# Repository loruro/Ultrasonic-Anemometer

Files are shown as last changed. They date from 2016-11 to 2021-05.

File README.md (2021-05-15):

# Ultrasonic Anemometer

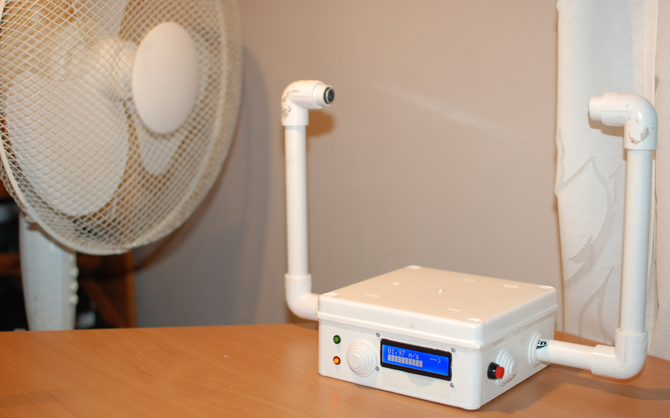
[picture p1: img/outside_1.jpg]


This is Ultrasonic Anemometer project based on AVR ATmega microcontroller.

## Principle of operation

Device measures wind velocity using ultrasounds. Two ultrasonic transducers installed on the end of both pipes send 40 kHz ultrasound signal between each other. Normally the velocity of this signal is the same for both directions. It is equal to the speed of sound, which depends mainly on the air temperature. For dry air and 1000 hPa pressure it can be calculated from:



where:
* vₚ - speed of sound [m/s]
* θ - air temperature [°C]

At 20 °C it is 343,96 m/s.

If there is a wind, it alters velocity of sound wave propagating in direction parallel to the wind:

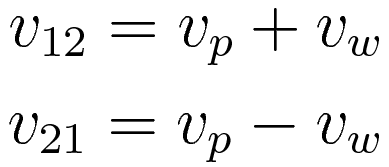
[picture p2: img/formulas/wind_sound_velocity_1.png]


where:
* v₁₂ - velocity of sound wave between point 1 and point 2
* v₂₁ - velocity of sound wave between point 2 and point 1
* vₚ - speed of sound
* vᵥᵥ - speed of wind

Above equations can be transformed into:

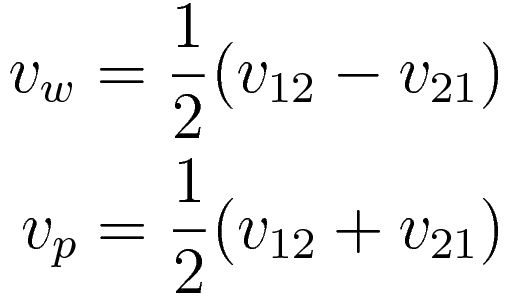
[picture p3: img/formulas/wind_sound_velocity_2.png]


The velocity of sound wave can be acquired by measuring time of flight of this wave between ultrasonic transducers. This is what this device does. First transducer emits ultrasonic impulse and second one receives it. Time between those events is measured and later the situation is reversed. Second transducers emits and first one receives.  
Knowing distance between those transducers, velocity of sound can be finally calculated.

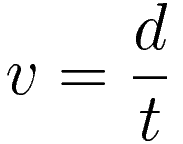
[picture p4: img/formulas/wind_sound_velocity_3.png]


where:
* d - distance between transducers
* t - time of flight

Velocities in previous equations can be substituted by above time formula:

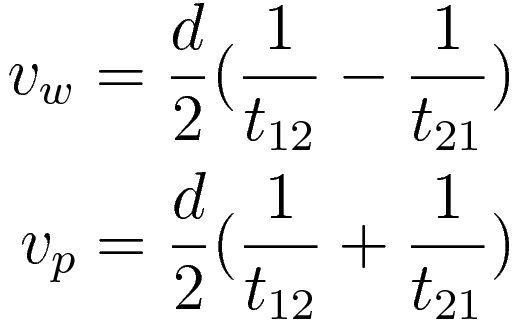
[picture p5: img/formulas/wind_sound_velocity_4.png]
  

Anemometer has only two ultrasonic transducers. Therefore, it can only measure wind speed in one direction (parallel to line containing both transducers). Measurement in more dimensions can be achievied by adding more transducers.

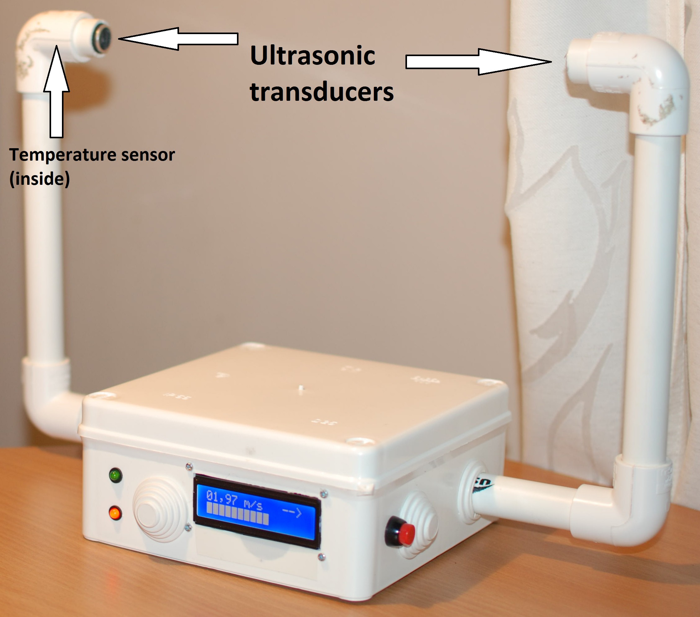
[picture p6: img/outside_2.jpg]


Device displays calculated wind speed and its direction on [HD44780 LCD](https://en.wikipedia.org/wiki/Hitachi_HD44780_LCD_controller) display. Under speed value there is a progress bar to next measured value. Unfortunately it takes quite a lot of time to perform all the signal processing calculations on this ATmega (about 46 seconds).  
Red LED is lit while power is supplied to the device. Green LED is blinking while the device is working correctly.  
Red button on the right performs calibration procedure. After pressing button for 2 seconds, [envelope](https://en.wikipedia.org/wiki/Envelope_%28waves%29) will be calculated of the next set of samples acquired by transducers. The result will be stored in EEPROM and used later for signal processing. This has to be done while there is no wind. Along with samples, temperature from DS1820 sensor is also acquired and stored. This calibration data will survive shutdown of the device because of storage in EEPROM.  
On the left side of the device there is a socket for power supply.

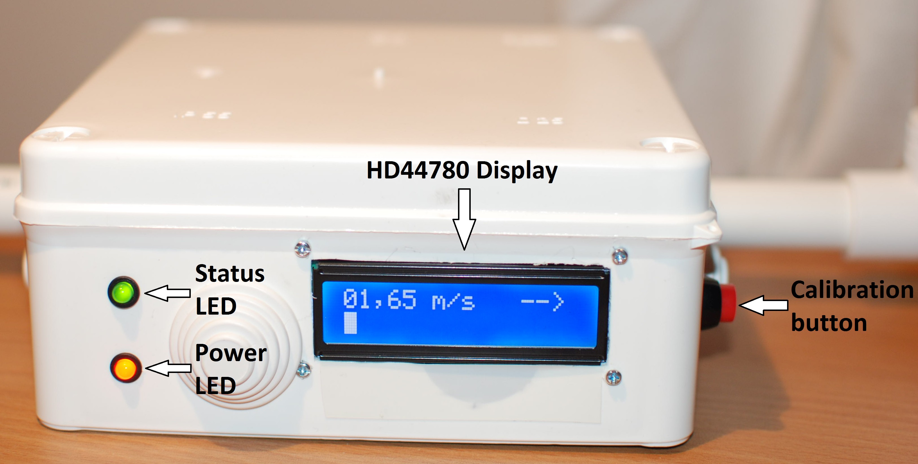
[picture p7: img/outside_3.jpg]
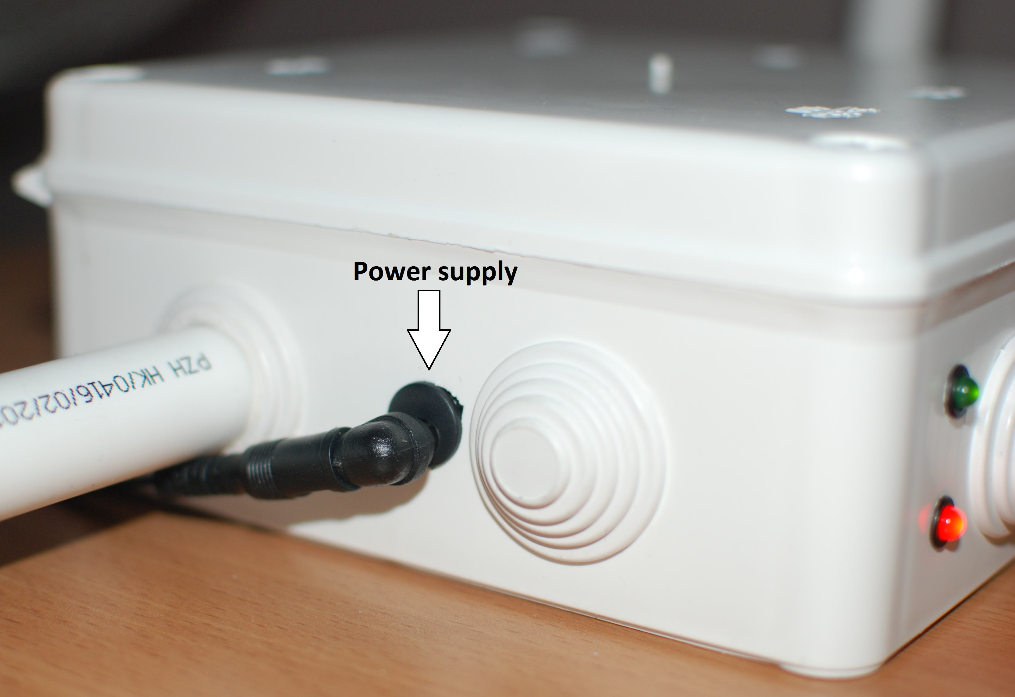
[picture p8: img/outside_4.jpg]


## Hardware

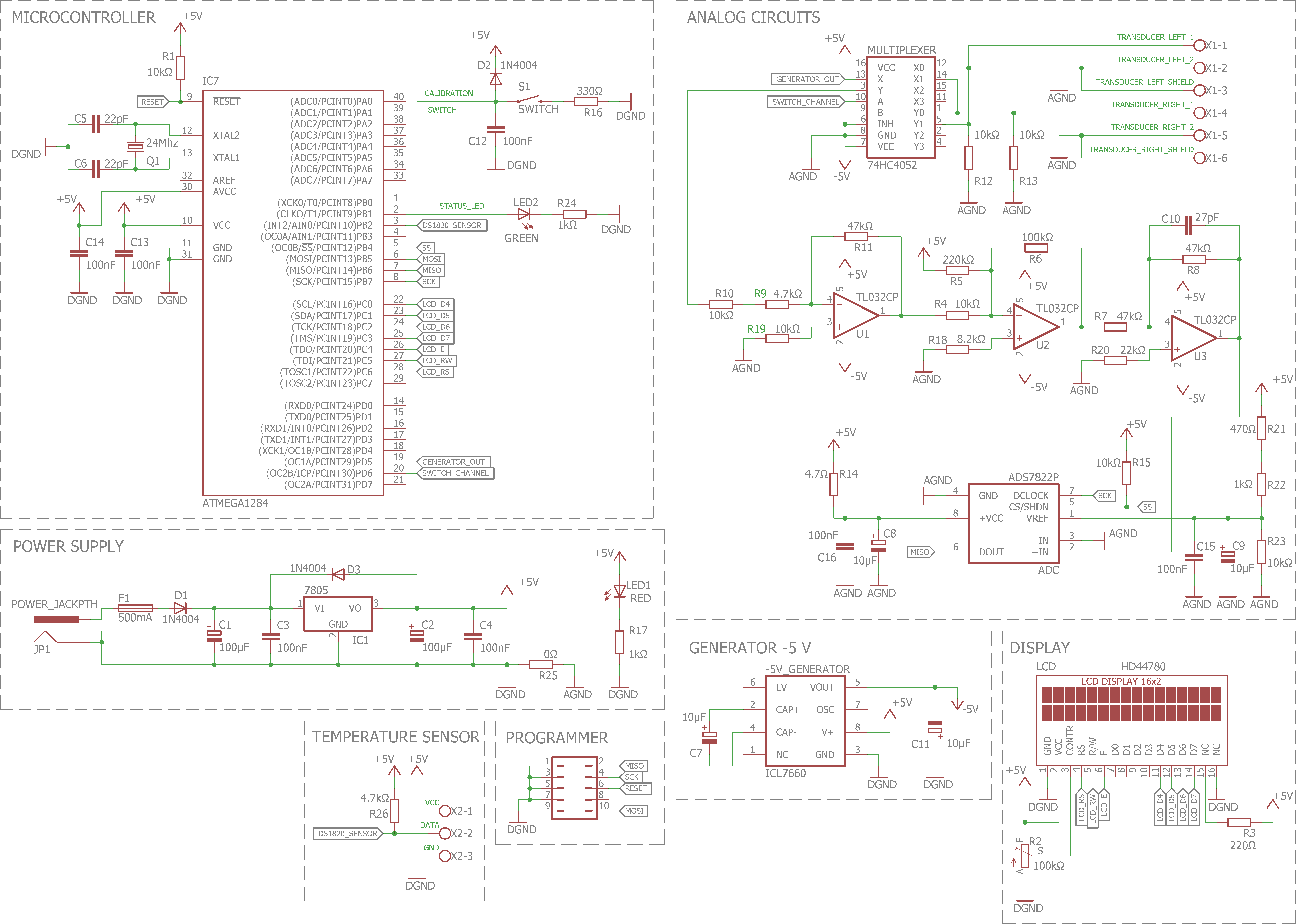
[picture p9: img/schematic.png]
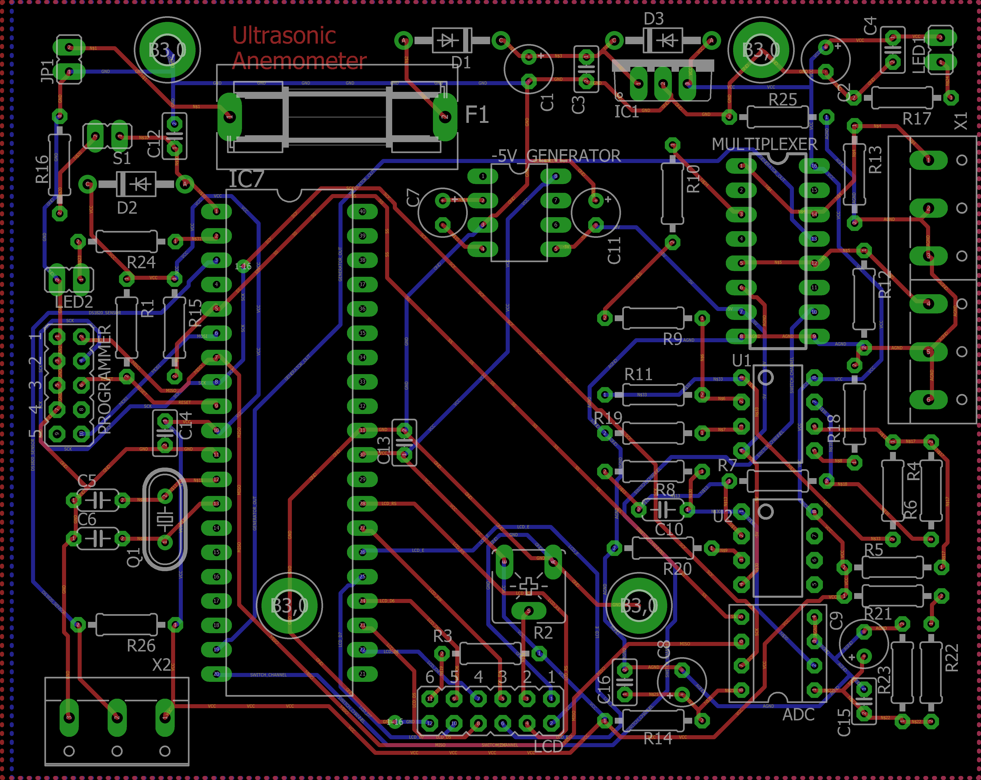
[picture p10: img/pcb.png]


Main part of the device is the AVR [ATmega1284](http://www.atmel.com/devices/atmega1284.aspx) microcontroller. It is slightly overclocked for a better performance. I used 24 MHz quartz crystal (official max. frequency is 20 MHz). Controller is programmed with ISP interface. I used simple and cheap [USBasp](http://www.fischl.de/usbasp/) programmer for it.  
Calibration button was connected together with resistor, capacitor and diode which do hardware [debouncing](https://en.wikipedia.org/wiki/Switch#Contact_bounce).  
All of the electronics are powered by 5 V supplied by onboard 7805 voltage regulator. It takes voltage straight from power socket. I used external 9 V power supply, but slightly higher voltage would be OK too (not too much to not overheat 7805 regulator). Along with it there is simple protection overcurrent and inverted voltage. Also there is ICL7660 -5 V voltage generator. It's used for powering multiplexer and operational amplifiers.  
HD44780 display is connected in 4-bit mode and busy bit reading.  
DS1820 temperature sensor uses 1-Wire interface, but has option for powering it via additional VDD pin. I used this option for better stability.  
Analog part of the device needs more explanation. Some of the signals here were measured by an oscilloscope. Microcontroller sends square wave through GENERATOR_OUT line to ultrasonic transducers.

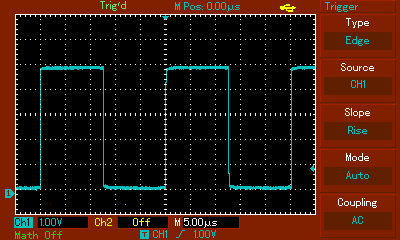
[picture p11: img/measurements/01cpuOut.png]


Multiplexer 74HC4052 directs it to either left or right transducer. Multiplexer is controlled by SWITCH_CHANNEL from ATmega. Transducers used in project are narrowband and designed for 40 kHz signal. Experimentally I found out that 40268 Hz signal gives the best amplitude. Transducers are connected with board by shielded cable. While signal from microcontroller is directed to one of them, signal from the other one is directed by multiplexer to amplifiers. Here is the signal before them:

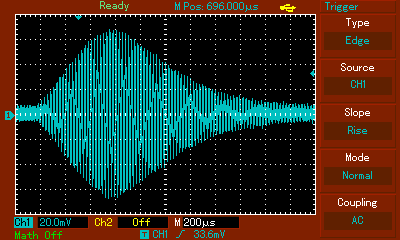
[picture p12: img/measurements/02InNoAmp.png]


First is an [inverting amplifier](https://en.wikipedia.org/wiki/Operational_amplifier_applications#Inverting_amplifier):



Amplified signal:

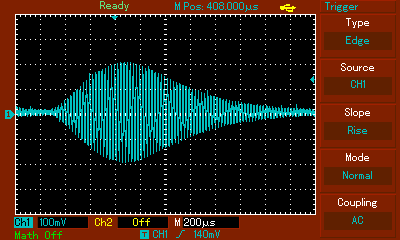
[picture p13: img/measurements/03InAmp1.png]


Later signal goes to [summing amplifier](https://en.wikipedia.org/wiki/Operational_amplifier_applications#Summing_amplifier), which again amplifies and adds offset to it. Entire signal has to be voltage positive because ADC used in the device cannot work with negative voltage.



Amplified signal:

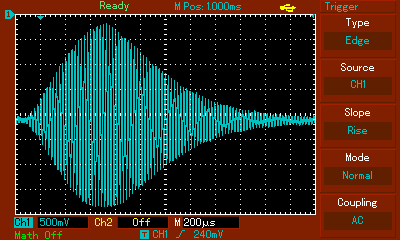
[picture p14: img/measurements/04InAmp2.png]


For final step I used [integrator](https://en.wikipedia.org/wiki/Operational_amplifier_applications#Inverting_integrator), which acts as low-pass filter. Any frequencies which are higher than our ultrasonic signal should be filtered out. Transfer function of the filter:



And its Bode plot:

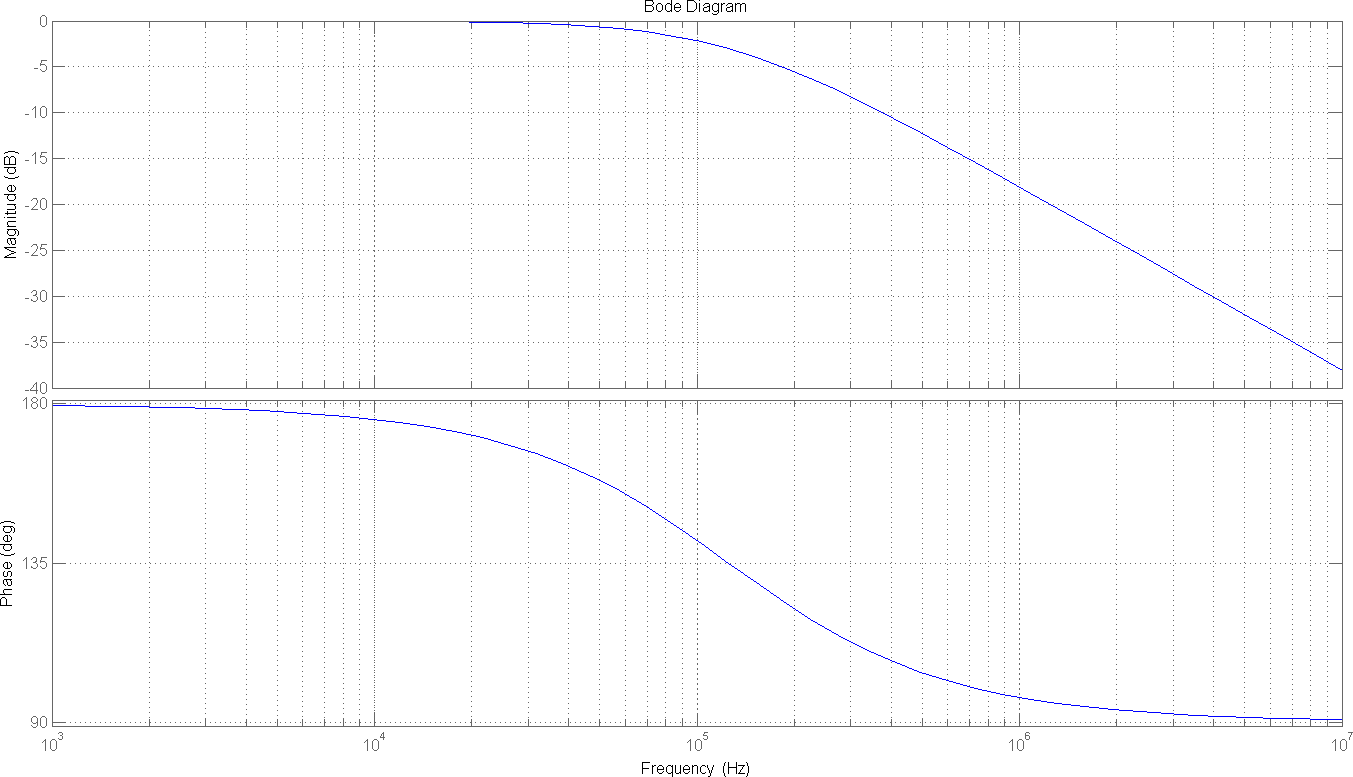
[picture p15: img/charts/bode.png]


Signal after filtering:

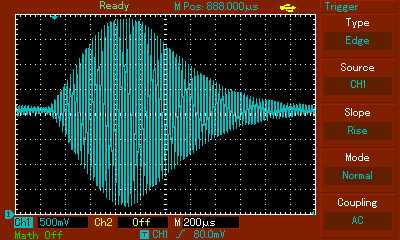
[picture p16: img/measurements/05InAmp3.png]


After all the operational amplifiers, signal finally goes to ADS7822P analog-to-digital converter. It sends converted digital signal to microcontroller through SPI interface. ATmega here is a master. This ADC has a resolution of 12 bits and max. frequency of 200 kHz. Because of clock dividers in ATmega and clock cycles needed to handle SPI, I managed to get sampling frequency of 157.9 kHz. [Nyquist–Shannon–Kotelnikov sampling theorem](https://en.wikipedia.org/wiki/Nyquist%E2%80%93Shannon_sampling_theorem) states that the sampling frequency should be at least 80536 Hz, so it is fulfilled. Analog signal has maximum value of about 4 V, so to increase voltage resolution I attached voltage divider to VREF pin of ADC, which gives voltage of about 4.359 V. This results in voltage resolution of 1.064 mV.  
Analog part of the device uses different ground than the rest of the device. It reduces noise derived from high frequency digital signals. Digital ground and analog ground are connected together at one point, close to the power supply.

Electrical schematic and PCB layout were designed using [EAGLE](https://cadsoft.io/) application. Tracks on PCB were designed using EAGLE Autorouter. That's why it's so ugly :)  
Photos of interior:

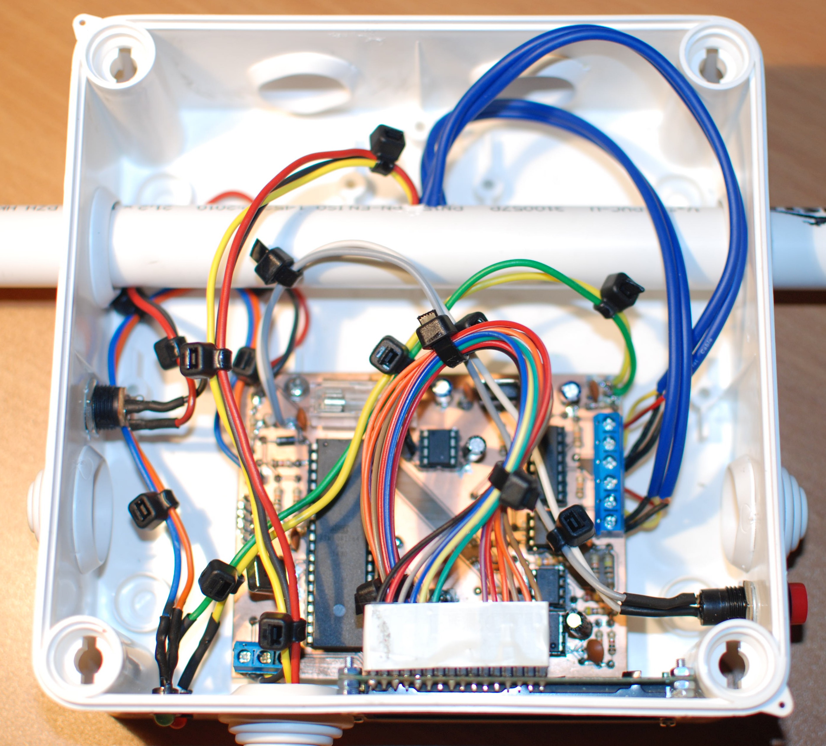
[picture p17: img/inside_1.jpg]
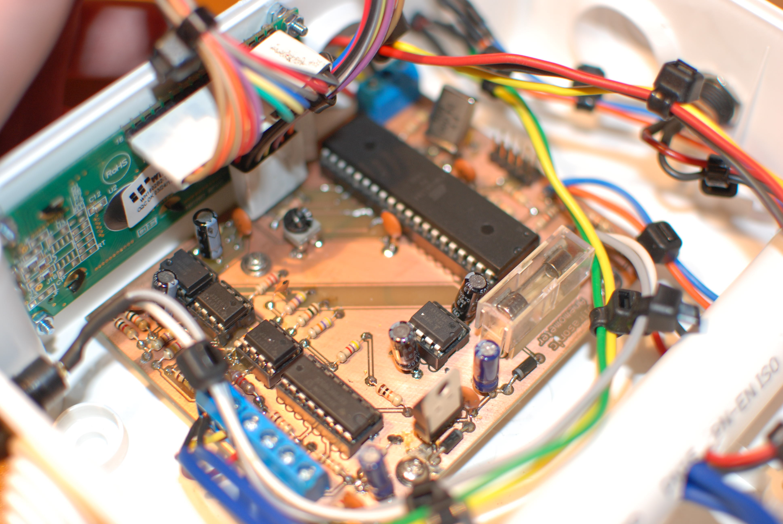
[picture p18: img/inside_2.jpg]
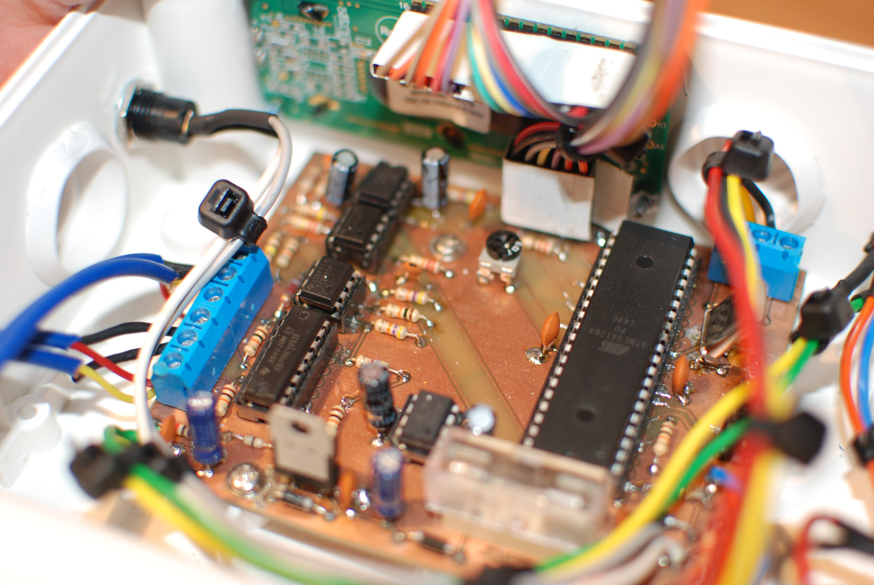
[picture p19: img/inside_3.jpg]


## Signal processing

After acquiring by microcontroller, digital samples look like this:

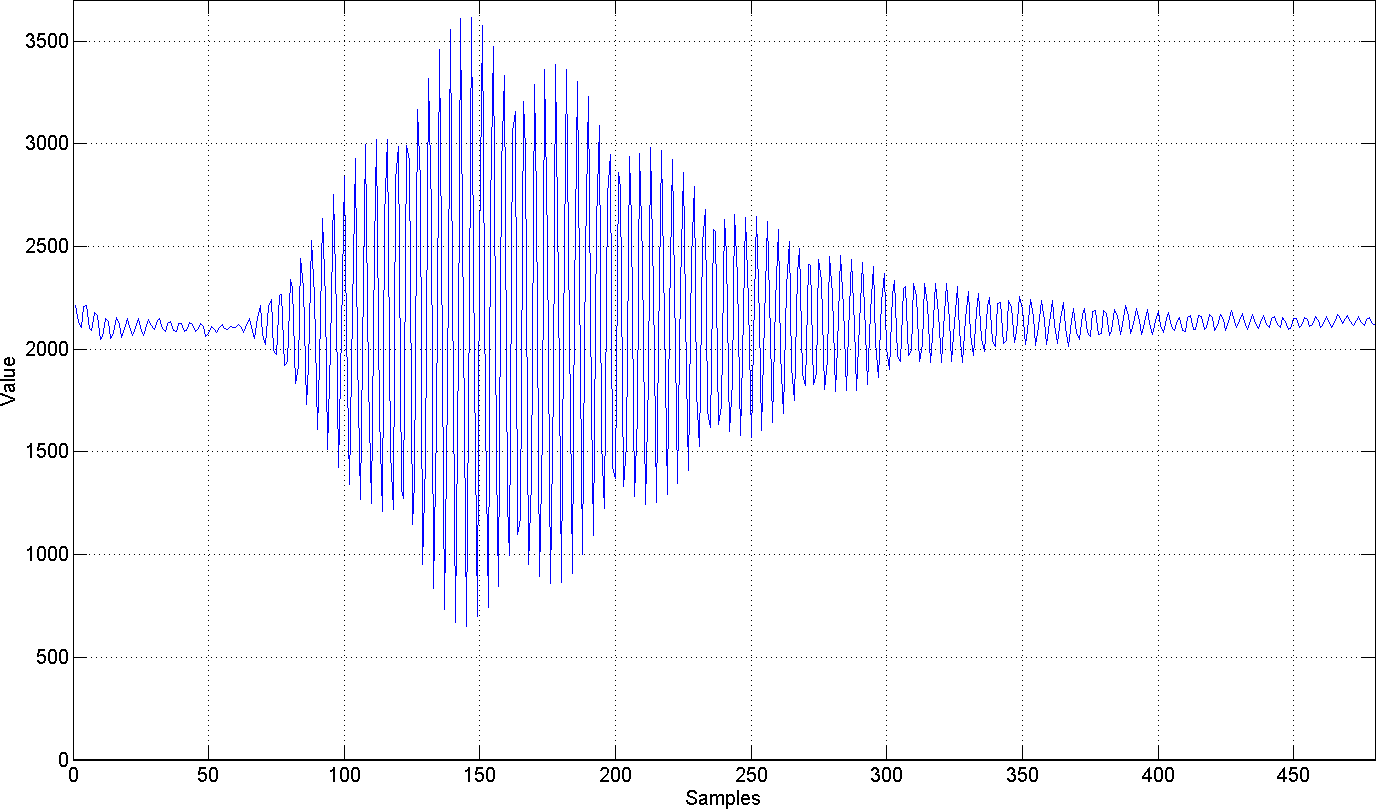
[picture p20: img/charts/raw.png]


Those samples should be analyzed without offset, so average value is calculated and subtracted from them:

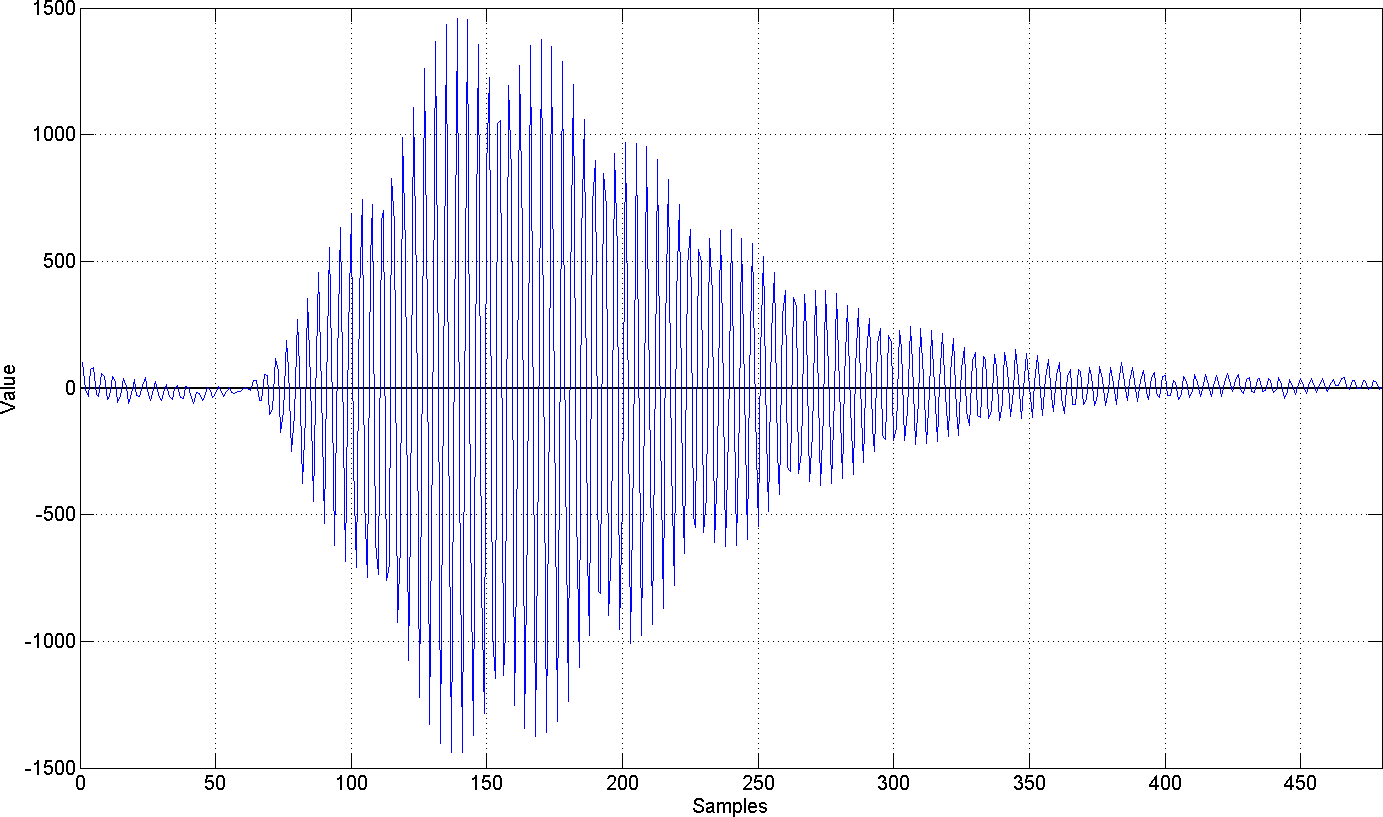
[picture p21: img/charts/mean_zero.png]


For getting precise time of flight of ultrasonic impulse I decided to calculate envelope of the acquired signal and [cross correlate](https://en.wikipedia.org/wiki/Cross-correlation) it with the calibration signal stored in EEPROM. To get envelope of signal, a magnitude of its [analytic representation](https://en.wikipedia.org/wiki/Analytic_signal) can be calculated. To get analytic signal, [Hilbert transform](https://en.wikipedia.org/wiki/Hilbert_transform) has to be calculated first. I used the following discrete formula to acquire it:

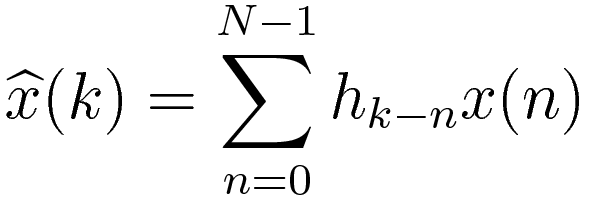
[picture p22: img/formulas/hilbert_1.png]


where:

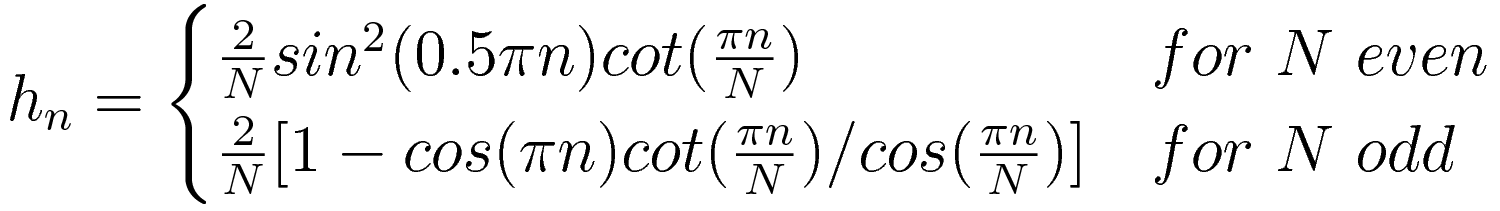
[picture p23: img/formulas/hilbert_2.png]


and
* x - original signal
* N - number of samples

Analytic signal can now be calculated with the following formula:



Result:

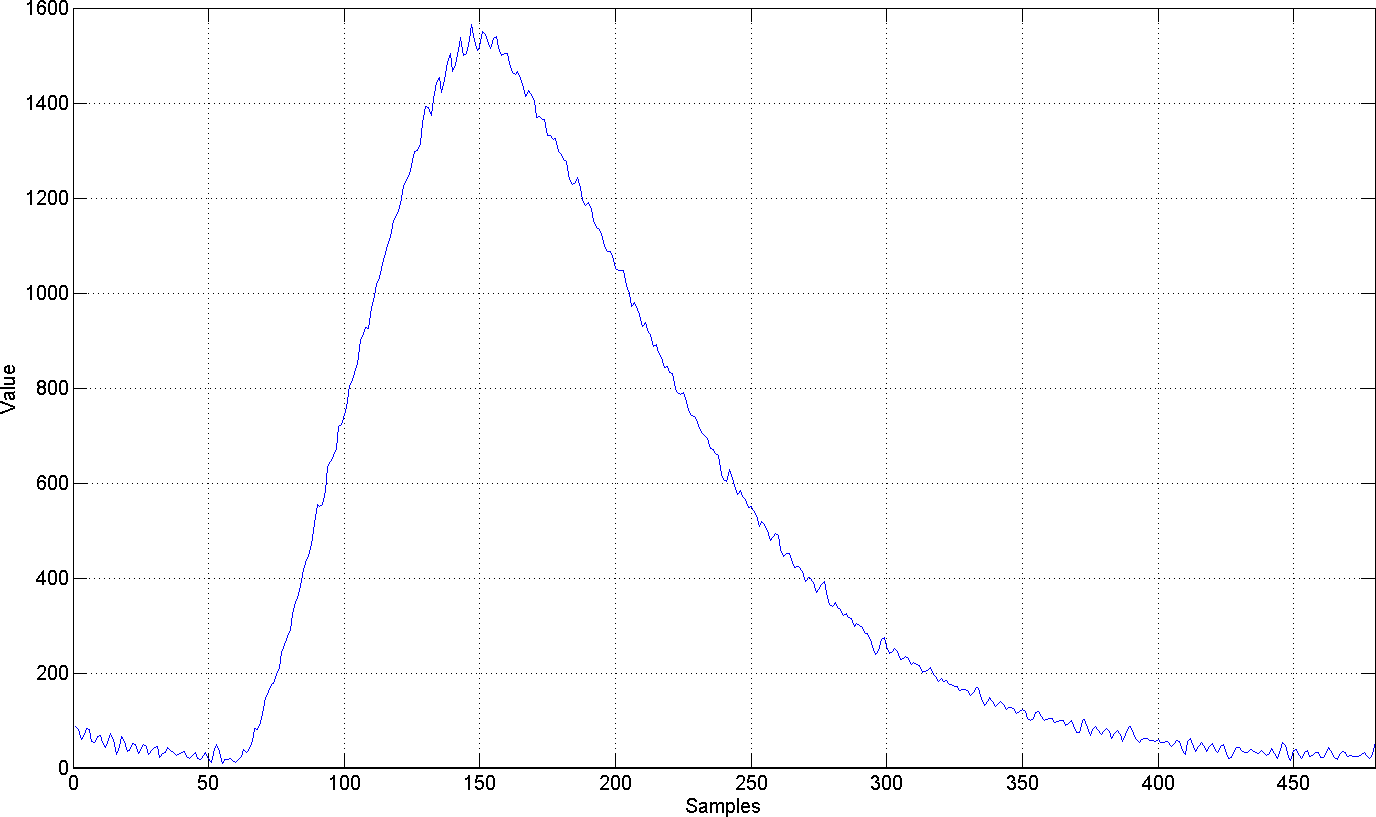
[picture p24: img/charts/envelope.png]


Now the envelope can be cross correlated with the envelope of calibration signal. I used following formula for discrete cross correlation:

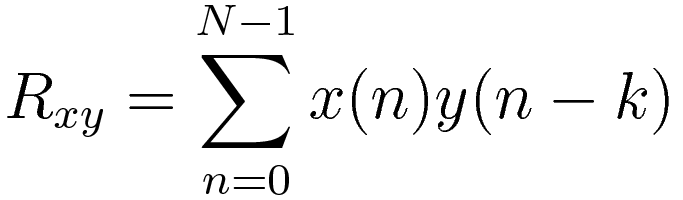
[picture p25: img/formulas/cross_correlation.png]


Distance between the maximal value and Y axis should determine time of flight of ultrasonic signal:

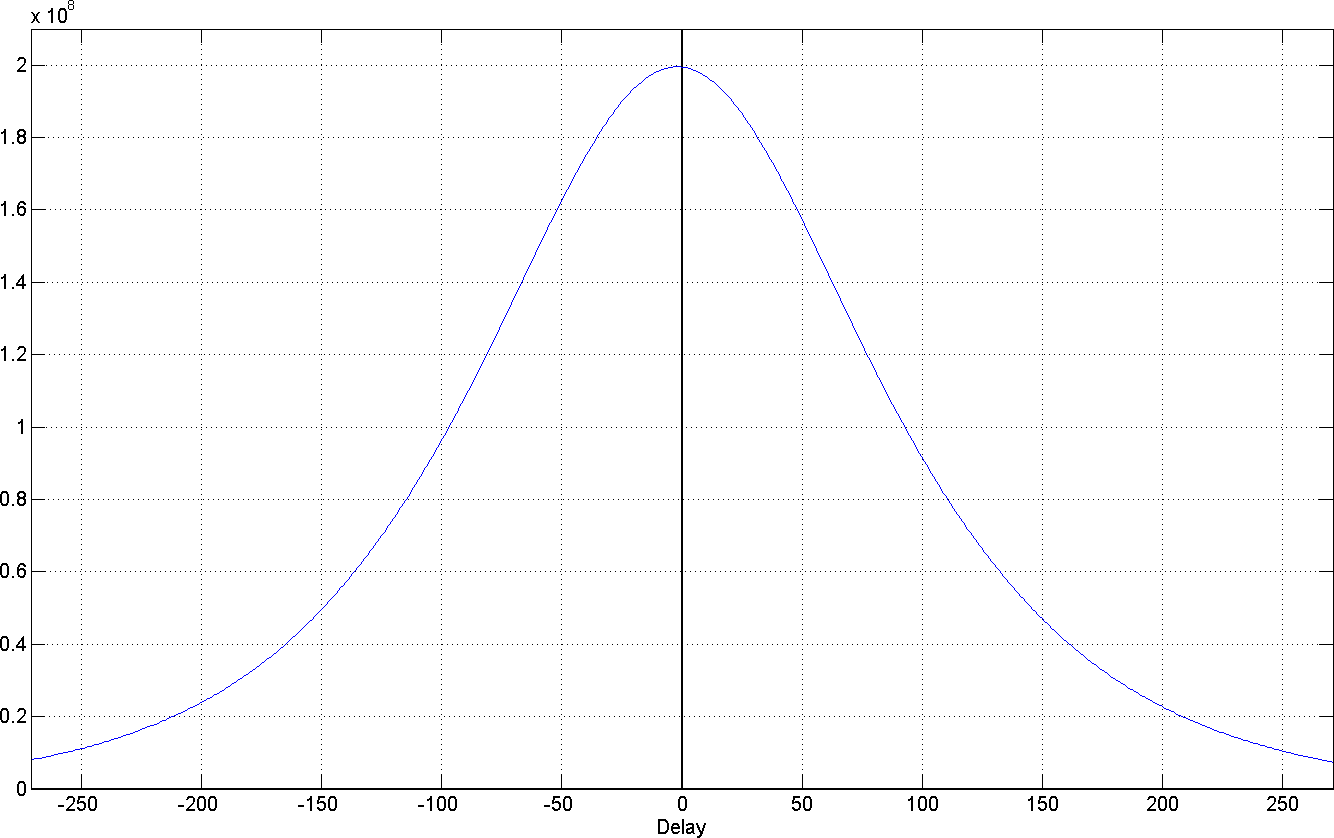
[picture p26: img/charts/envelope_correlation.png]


I also tried calculating only the cross correlation of present and calibration signals, but results were far from being correct. I also tried calculating cross correlation first and then the envelope of it. Results were almost as good as the currently used method, but still they were worse.

I observed that the top part of the calculated cross correlation looks similar to quadratic function. To increase resolution and extract more information from it I decided to use quadratic regression. 31 highest samples are used to approximate quadratic function using following formulas:

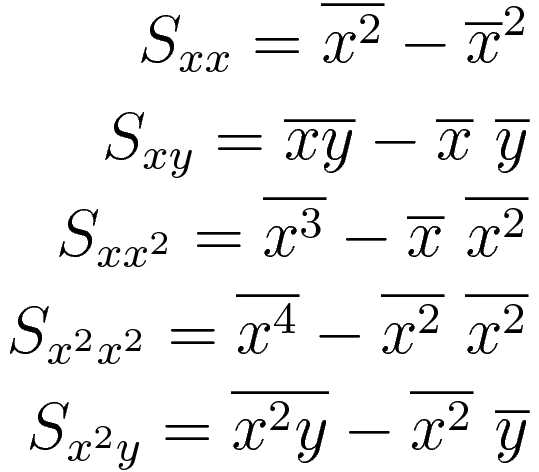
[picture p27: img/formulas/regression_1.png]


where:
* x - function arguments
* y - function value
* ( ¯ ) - average value

Coefficients can now be calculated (coefficient C is not needed):

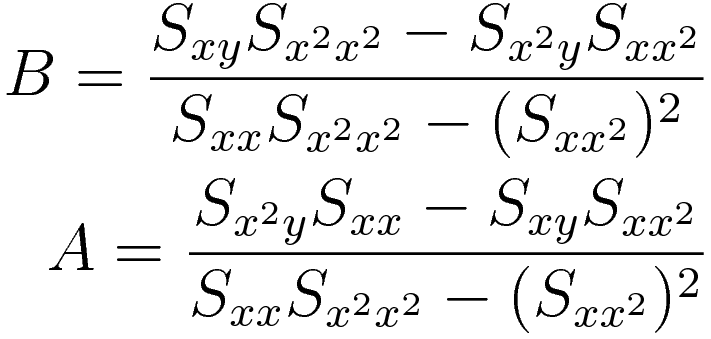
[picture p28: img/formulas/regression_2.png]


And finally maximum of the function can be calculated:

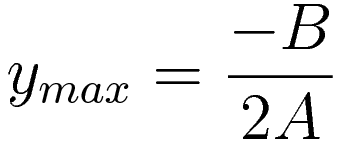
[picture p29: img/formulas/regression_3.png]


This maximum is used to calculate the time of flight. Here is comparison of signal and approximated quadratic function:

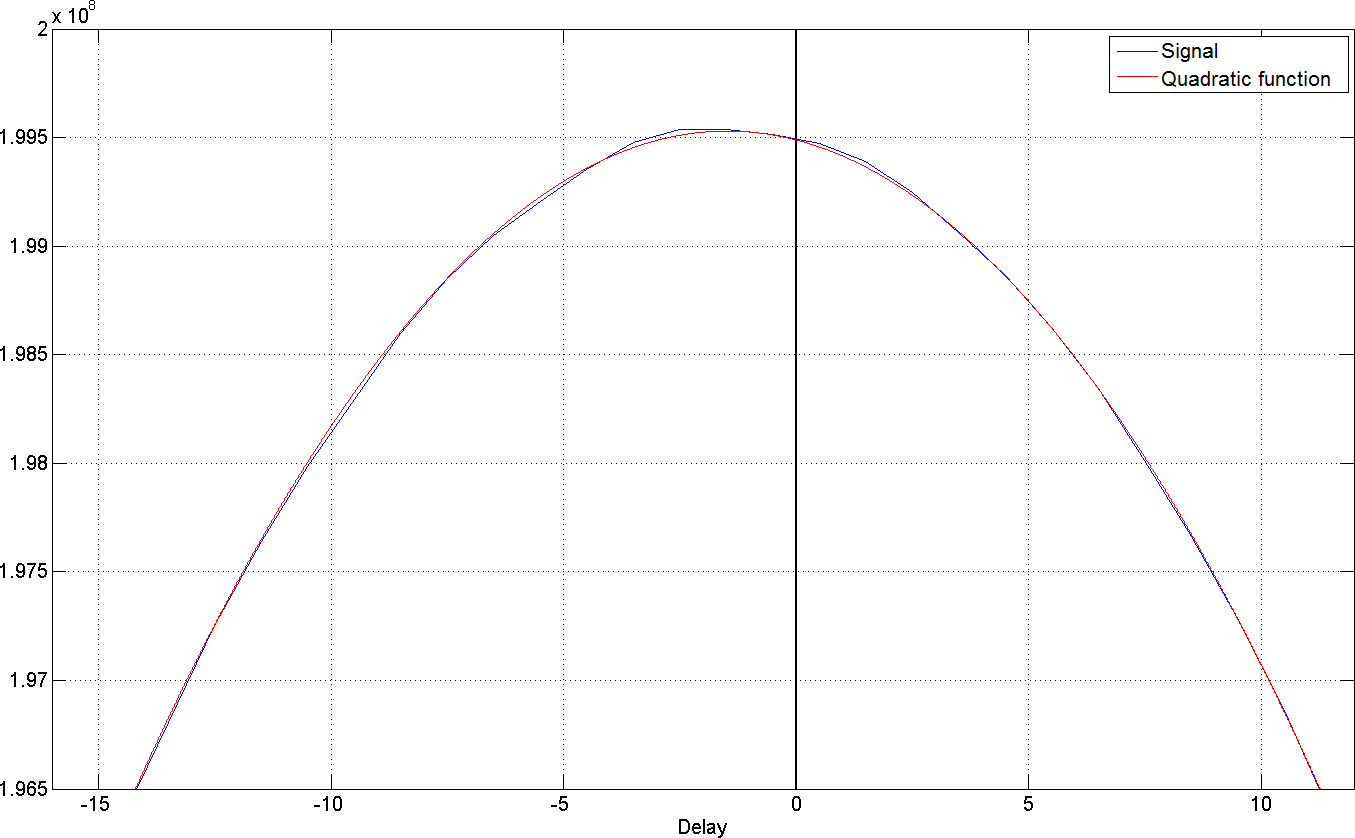
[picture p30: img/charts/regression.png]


Distance between the maximal value and Y axis multiplied by 6333 ns results only in signal time of flight difference between conditions with wind and without wind. To get total time of fligh there has to be added time of flight during windless conditions. This time is calculated using temperature acquired during calibration by using formula from the beggining of the article. Distance between transducers also has to be known. It's 27 cm. Any later temperature changes should not affect the final result.  
Knowing the total signal time of flight, final wind speed value is calculated.

## Software

Software for the ATmega1284 microcontroller was developed using Atmel Studio IDE with AVR8 GNU Toolchain. It contains avr-libc libraries and avr-gcc compiler. Optimization flag **_-Os_** was set for compilation. All used flags are below:
```shell
avr-gcc -x c -funsigned-char -funsigned-bitfields -DNDEBUG -DF_CPU=24000000UL -Os -ffunction-sections -fdata-sections -fpack-struct -fshort-enums -mrelax -Wall -mmcu=atmega1284 -c -std=gnu99 -MD -MP -MF "$(@:%.o=%.d)" -MT"$(@:%.o=%.d)" -MT"$(@:%.o=%.o)"
```
Fuse bits are configured as follows:

| Fuse Low | Fuse High | Extended Fuse |
| :---: |:---:| :---: |
| 0xF7 | 0xD1 | 0xFC |

Pretty online fuse calculator showing this configuration is [here](http://eleccelerator.com/fusecalc/fusecalc.php?chip=atmega1284p&LOW=F7&HIGH=D1&EXTENDED=FC&LOCKBIT=FF). Fuse Low is configured to allow clock source from 24 MHz quartz crystal. Fuse High, among other things, disables JTAG interface, so more pins can be used as GPIO. Extended Fuse enables Brown-out detection at level 4.3 V.

One of the most important fragment of code is shown below:
```c
inline void getDataFromAdc(uint16_t *data) {
  // Activating ADC.
  SPI_SS_LOW;
  // Starting transmission.
  SPDR = 0x00;

  // Waiting for end of transmission.
  // NOP causes loop to check end of transmission flag at the most optimal time.
  asm volatile("nop"::);
  while(!(SPSR & _BV(SPIF)));

  // Starting another transmission.
  SPDR = 0x00;
  // Saving byte from previous transmission.
  *((uint8_t*)data + 1) = SPDR;

  // Waiting for end of transmission. This time three NOP's were needed.
  asm volatile(
    "nop\n\t"
    "nop\n\t"
    "nop\n\t"::
  );
  while(!(SPSR & _BV(SPIF)));

  // Saving byte from transmission.
  *((uint8_t*)data + 0) = SPDR;
  // Deactivating ADC.
  SPI_SS_HIGH;
}
```
This function is responsible for acquiring samples from ADC. Execution time of it is significant, because sampling frequency depends on it. <i>SPI_SS_LOW</i> macro drives SS line low on SPI interface. It enables ADC. Afterwards, writing 0 to SPDR register begins transmission. Microcontroller is transmitting this 0 over MOSI line (which is not even connected to ADC), but at the same time, it receives data byte over MISO line. <i>while(!(SPSR & _BV(SPIF)))</i> waits for the end of transmission. Because checking for SPIF flag in loop takes a few clock cycles, adding <i>asm volatile("nop"::)</i> ensures that the flag is checked right after end of transmission. This solution was found by analyzing assembly code during simulator debugging. Right after that, another transmission starts. Afterwards, previous byte is saved in variable. SPDR register for transmitted byte is different than SPDR for received byte, so this sequence was used just to save some clock cycles. SPIF is checked again for end of transmission, but now three NOPs were needed. Later, new byte is saved in variable and <i>SPI_SS_HIGH</i> drives SS line high and disables ADC. Restarting ADC is needed between every sample.

Generated assembly from above code is shown below:
```nasm
cbi    0x05, 4
out    0x2e, r1
nop
in     r0, 0x2d
sbrs   r0, 7
rjmp   .-6
out    0x2e, r1
in     r18, 0x2e
movw   r30, r24
subi   r30, 0xA7
sbci   r31, 0xFE
std    Z+1, r18
nop
nop
nop
in     r0, 0x2d
sbrs   r0, 7
rjmp   .-6
in     r18, 0x2e
st     Z, r18
sbi    0x05, 4
adiw   r24, 0x02
cpi    r24, 0xC0
ldi    r18, 0x03
cpc    r25, r18
brne   .-52
```
Execution of this code takes exactly 152 clock cycles. For 24 MHz clock, it gives 6333 ns. It is equivalent to sampling frequency of 157.9 MHz.

In this program there are no floating point numbers, because ATmega microcontrollers don't have hardware support for them, which would result in very long computation time and large memory consumption. Trigonometric functions needed for calculations were implemented as lookup tables.

## Conclusion

I tested the device with typical household fan. Result of the measurements seem to be OK. Unfortunately I don't have access to any professional hardware, which would verify it.  
46 seconds needed for calculating wind speed is a bit too long time. More powerful microcontroller should have been used or a different signal processing method. ATmega microcontrollers are very slow comparing to modern ones.  
Despite it, while creating this device I learned many new things about electronics, digital signal processing and programming embedded systems in C. Also I Learned how does ultrasonic anemometer works.

<br /><span xmlns:dct="http://purl.org/dc/terms/" property="dct:title">Ultrasonic Anemometer</span> by <span xmlns:cc="http://creativecommons.org/ns#" property="cc:attributionName">Karol Leszczyński</span> is licensed under a <a rel="license" href="http://creativecommons.org/licenses/by-sa/4.0/">Creative Commons Attribution-ShareAlike 4.0 International License</a>.

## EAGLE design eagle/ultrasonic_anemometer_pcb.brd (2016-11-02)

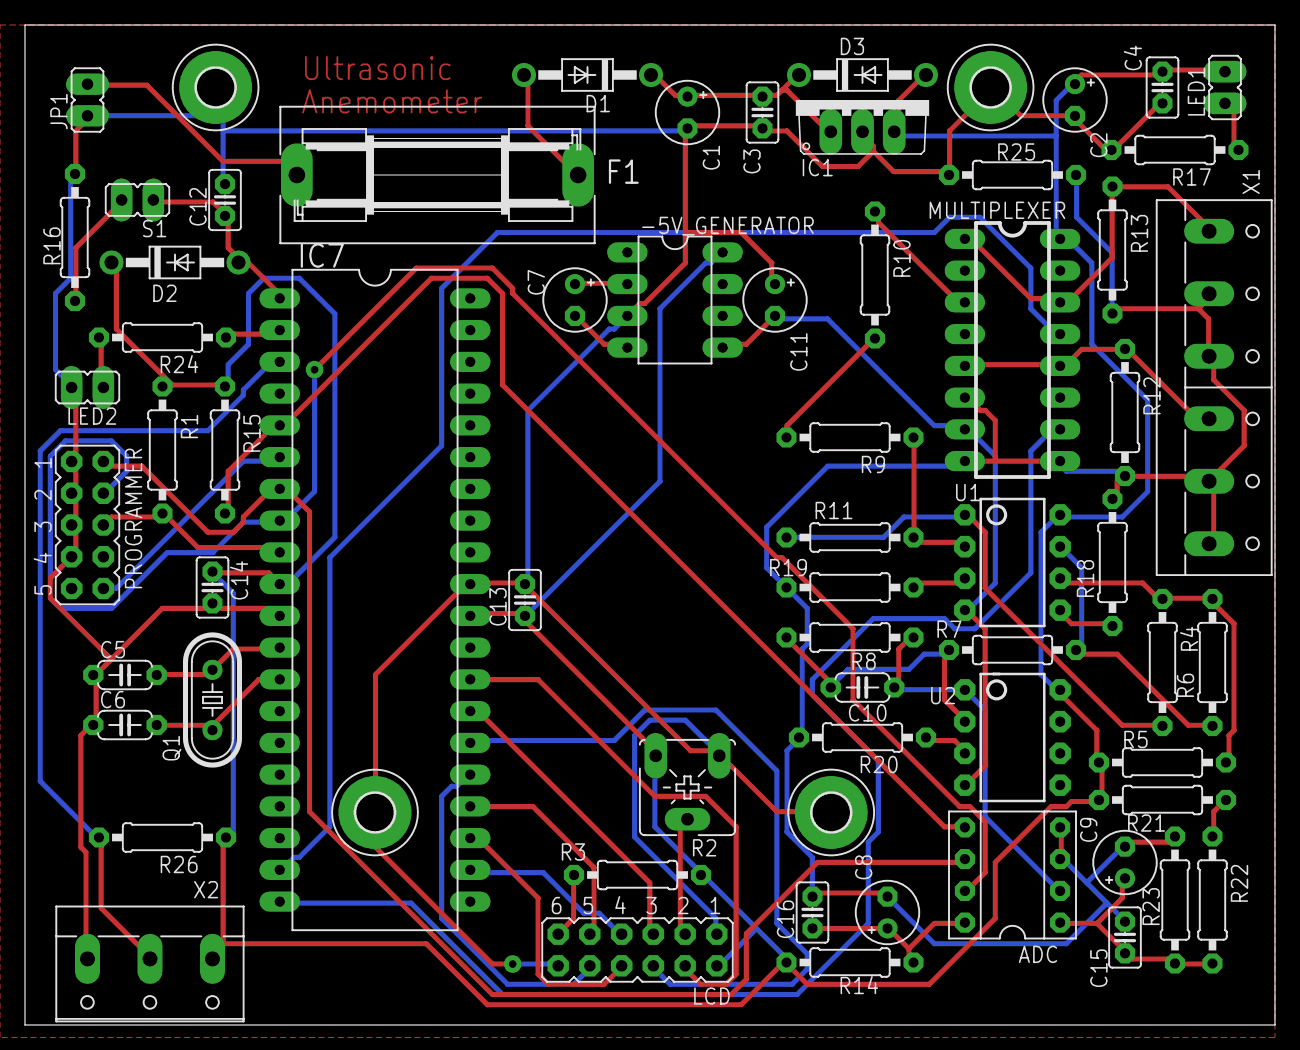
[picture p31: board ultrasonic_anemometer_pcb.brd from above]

Board: 2 copper layers, 100.0 x 80.0 mm, 66 parts (0 on the bottom side), 49 nets.

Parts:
-5V_GENERATOR: ICL7660; DIL08
ADC: ADS7822P; DIL08
C1, C2: 100μF; E2,5-5
C3, C4, C12, C13, C14, C15, C16: 100nF; C025-025X050
C5, C6: 22pF; C050-024X044
C7, C8, C9, C11: 10μF; E2,5-5
C10: 18pF; C050-024X044
D1, D2, D3: 1N4004; DO41-10
F1: SH22,5A
H1, H2, H3, H4: MOUNT-PAD-ROUND3.0; 3,0-PAD
IC1: 7805; TO220V
IC7: ATMEGA1284; DIL40
JP1: JP1
LCD: JP6Q
LED1, LED2: JP1
MULTIPLEXER: 74HC4052; DIL16
PROGRAMMER: JP5Q
Q1: 25Mhz; HC49/S
R1, R4, R7, R8, R10, R12, R13, R15, R19, R23: 10kΩ; 0207/10
R2: 100kΩ; CA6V
R3: 220Ω; 0207/10
R5: 220kΩ; 0207/10
R6: 100kΩ; 0207/10
R9, R20, R26: 4.7kΩ; 0207/10
R11: 47kΩ; 0207/10
R14: 4.7Ω; 0207/10
R16: 330Ω; 0207/10
R17, R22, R24: 1kΩ; 0207/10
R18: 8.2kΩ; 0207/10
R21: 470Ω; 0207/10
R25: 0Ω; 0207/10
S1: JP1
U1, U2: OPAMP-DUALDIP; DIP08
X1: W237-6
X2: W237-103

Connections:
-5V: -5V_GENERATOR.5, C11.-, MULTIPLEXER.7, U1.4, U2.4
AGND: ADC.3, ADC.4, C8.-, C9.-, C15.1, C16.2, MULTIPLEXER.6, MULTIPLEXER.8, MULTIPLEXER.9, R12.2, R13.2, R18.2, R19.2, R20.2, R23.2, R25.1, X1.2, X1.3, X1.5, X1.6
DS1820_SENSOR: IC7.3, R26.2, X2.2
GENERATOR_OUT: IC7.19, MULTIPLEXER.13
GND: -5V_GENERATOR.3, C1.-, C2.-, C3.2, C4.2, C5.1, C6.1, C11.+, C12.2, C13.2, C14.2, H1.B3,0, H2.B3,0, H3.B3,0, H4.B3,0, IC1.2, IC7.11, IC7.31, JP1.1, LCD.1, LCD.12, LED2.2, PROGRAMMER.1, PROGRAMMER.3, PROGRAMMER.5, PROGRAMMER.7, R2.A, R16.1, R17.2, R25.2, X2.3
LCD_D4: IC7.22, LCD.7
LCD_D5: IC7.23, LCD.8
LCD_D6: IC7.24, LCD.9
LCD_D7: IC7.25, LCD.10
LCD_E: IC7.26, LCD.6
LCD_RS: IC7.28, LCD.4
LCD_RW: IC7.27, LCD.5
MISO: ADC.6, IC7.7, PROGRAMMER.2
MOSI: IC7.6, PROGRAMMER.10
unnamed: F1.1, JP1.2
unnamed: D1.A, F1.2
unnamed: C1.+, C3.1, D1.C, D3.C, IC1.1
unnamed: MULTIPLEXER.1, MULTIPLEXER.14, R13.1, X1.1
unnamed: MULTIPLEXER.5, MULTIPLEXER.12, R12.1, X1.4
unnamed: R9.1, R11.2, U1.2
unnamed: R19.1, U1.3
unnamed: R18.1, U1.5
unnamed: R20.1, U2.3
unnamed: C12.1, D2.A, IC7.1, S1.1
unnamed: C5.2, IC7.12, Q1.2
unnamed: C6.2, IC7.13, Q1.1
unnamed: C10.2, R7.1, R8.2, U2.2
unnamed: -5V_GENERATOR.2, C7.+
unnamed: -5V_GENERATOR.4, C7.-
unnamed: R9.2, R10.2
unnamed: R4.1, R5.1, R6.2, U1.6
unnamed: R6.1, R7.2, U1.7
unnamed: LCD.11, R3.2
unnamed: R16.2, S1.2
unnamed: LCD.3, R2.S
unnamed: ADC.1, C9.+, C15.2, R22.2, R23.1
unnamed: LED2.1, R24.2
unnamed: LED1.1, R17.1
unnamed: ADC.8, C8.+, C16.1, R14.2
unnamed: R21.2, R22.1
unnamed: ADC.2, C10.1, R8.1, U2.1
unnamed: IC7.2, R24.1
unnamed: R4.2, R11.1, U1.1
unnamed: MULTIPLEXER.3, R10.1
RESET: IC7.9, PROGRAMMER.6, R1.2
SCK: ADC.7, IC7.8, PROGRAMMER.4
SS: ADC.5, IC7.5, R15.2
SWITCH_CHANNEL: IC7.20, MULTIPLEXER.10
VCC: -5V_GENERATOR.8, C2.+, C4.1, C13.1, C14.1, D2.C, D3.A, IC1.3, IC7.10, IC7.30, LCD.2, LED1.2, MULTIPLEXER.16, R1.1, R2.E, R3.1, R5.2, R14.1, R15.1, R21.1, R26.1, U1.8, U2.8, X2.1

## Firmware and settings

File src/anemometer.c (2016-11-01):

/**
  ******************************************************************************
  * @file    anemometer.c
  * @author  Karol Leszczyński
  * @version V1.0.0
  * @date    08-August-2015
  * @brief   Main program file.
  ******************************************************************************
  * @attention
  *
  * This file is part of Ultrasonic_Anemometer.
  *
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
  ******************************************************************************
  */

#include "anemometer.h"

#include <avr/interrupt.h>
#include <avr/wdt.h>
#include <stdio.h>
#include <util/delay.h>

#include "ads7822.h"
#include "calibrationEEPROM.h"
#include "lcd.h"
#include "signalProcessing.h"

// Flag indicating end of data collection.
bool dataCollected = false;

// Collected data.
uint16_t samplesTmp[SAMPLE_NUMBER];

/**
  * @brief  Generator and multiplexer initialization.
  * @retval Void.
  */
void timerGeneratorInit(void);

/**
  * @brief  Status LED initialization.
  * @retval Void.
  */
void timerLedInit(void);

/**
  * @brief  Calibration button initialization.
  * @retval Void.
  */
void timerCalibrationInit(void);

/**
  * @brief  Initialization.
  * @retval Void.
  */
void init(void);

/**
  * @brief  Starts ultrasound generator.
  * @retval Void.
  */
void startGenerator(void);

/**
  * @brief  Saves first signal.
  * @param  samples Pointer to a Samples structure.
  * @retval Void.
  */
void saveFirstDataset(Samples *samples);

/**
  * @brief  Saves second signal and partly processes data.
  * @param  samples Pointer to a Samples structure.
  * @retval Void.
  */
void saveSecondDatasetAndProcessData(Samples *samples);

/**
  * @brief  Does the rest of data processing and calculates wind value.
  * @param  samples Pointer to a Samples structure.
  * @retval Void.
  */
void continueProcessData(Samples *samples);

/**
  * @brief  Calculates signal time of flight without wind.
  * @param  temperature Measured temperature.
  * @retval Calculated time of flight.
  */
inline uint64_t calcTimeWithoutWind(int8_t temperature);

/**
  * @brief  Main function.
  * @retval Should not return.
  */
int main(void) {
  init();

  Samples samples = {
    .samplesNumber = SAMPLE_NUMBER
  };

  // Loading calibration data from EEPROM.
  loadDataFromEeprom(&samples);
  samples.timeWithoutWind = calcTimeWithoutWind(samples.temperature);
  putText("INITIALIZED");

  while(1) {
    static bool sendUltrasoundFlag = true;
    static bool collectSecondDatasetFlag = false;

    // Send ultrasonic impulse.
    if(sendUltrasoundFlag) {
      sendUltrasoundFlag = false;
      startGenerator();
    }

    // Received signal.
    if(dataCollected) {
      dataCollected = false;

      // Received only first signal.
      if(!collectSecondDatasetFlag) {
        saveFirstDataset(&samples);
        collectSecondDatasetFlag = true;
        sendUltrasoundFlag = true;
      } else {
        collectSecondDatasetFlag = false;
        saveSecondDatasetAndProcessData(&samples);

        // Signal will be saved as calibration data.
        if(calibrationInProgress) {
          saveCalibratedData(&samples);
          samples.timeWithoutWind = calcTimeWithoutWind(samples.temperature);
          sendUltrasoundFlag = true;
        } else {
          continueProcessData(&samples);
          sendUltrasoundFlag = true;
        }
      }
    }
  }
  return 0;
}

void timerGeneratorInit(void) {
  // Setting generator pin as output.
  GENERATOR_PORT &= ~_BV(GENERATOR_OUT);
  GENERATOR_DDR |= _BV(GENERATOR_OUT);
  // Setting multiplexer pin as output.
  GENERATOR_PORT &= ~_BV(MPLEXER_SWITCH);
  GENERATOR_DDR |= _BV(MPLEXER_SWITCH);

  // Toggles generator pin on timer compare match.
  TCCR1A |= _BV(COM1A0);
  // CTC mode.
  TCCR1B |= _BV(WGM12);
  OCR1A = GENERATOR_TIMER_TICKS;
  // Interrupt on compare match.
  TIMSK1 |= _BV(OCIE1A);
}

void timerLedInit(void) {
  // Setting LED pin as output.
  LED_PORT &= ~_BV(LED);
  LED_DDR |= _BV(LED);
}

void timerCalibrationInit(void) {
  // Sets prescaler to 1024.
  TCCR0B |= _BV(CS02) | _BV(CS00);
  // Interrupt on overflow.
  TIMSK0 |= _BV(TOIE0);
}

void init(void) {
  // Enabling Watchdog.
  wdt_enable(WDTO_8S);

  // Setting pullup resistors for all pins.
  PORTA = 0xFF;
  PORTB = 0xFF;
  PORTC = 0xFF;
  PORTD = 0xFF;

  lcdInit();
  putText("INITIALIZING");
  timerGeneratorInit();
  timerCalibrationInit();
  spiInit();
  timerLedInit();
  // Enabling global interrupts.
  sei();
}

void startGenerator(void) {
  TCNT1 = 0; 
  // Starting timer (without prescaler).
  TCCR1B |= _BV(CS10);
}

void saveFirstDataset(Samples *samples) {
  // Converting raw data received from ADC.
  for(uint16_t i = 0; i < SAMPLE_NUMBER; i++) {
    samplesTmp[i] >>= 1;
    samplesTmp[i] &= 0x0FFF;
    samples->left[i] = samplesTmp[i];
  }

  // Switching multiplexer.
  GENERATOR_PORT |= _BV(MPLEXER_SWITCH);
}

void saveSecondDatasetAndProcessData(Samples *samples) {
  // Switching multiplexer.
  GENERATOR_PORT &= ~_BV(MPLEXER_SWITCH);

  uint32_t meanLeft = 0;
  uint32_t meanRight = 0;

  // Converting raw data received from ADC.
  for(uint16_t i = 0; i < SAMPLE_NUMBER; i++) {
    samplesTmp[i] >>= 1;
    samplesTmp[i] &= 0x0FFF;
    samples->right[i] = samplesTmp[i];
    
    meanLeft += samples->left[i];
    meanRight += samples->right[i];
  }

  meanLeft /= SAMPLE_NUMBER;
  meanRight /= SAMPLE_NUMBER;

  // Subtracting mean value of signal.
  for(uint16_t i = 0; i < SAMPLE_NUMBER; i++) {
    samples->left[i] -= meanLeft;
    samples->right[i] -= meanRight;
  }

  // Calculating envelopes of signals.
  envelope(samples);
}

void continueProcessData(Samples *samples) {
  Processed processed = {
    .deltaTimeLeft = 0,
    .deltaTimeRight = 0,
    .highestCorrelationLeft = {0},
    .highestCorrelationRight = {0},
    .highestCorrelationLength = REGRESSION_SAMPLES
  };

  // Calculating cross correlation of signals.
  crossCorrelation(samples,  &processed, MAX_DELAY);

  // Calculating delay (in ns) between cross correlated signals.
  processed.deltaTimeLeft *= 6333;
  processed.deltaTimeRight *= 6333;

  // Interpolating for better delay.
  processed.deltaTimeLeft += quadRegression(processed.highestCorrelationLeft,
                                            REGRESSION_SAMPLES);
  processed.deltaTimeRight += quadRegression(processed.highestCorrelationRight,
                                             REGRESSION_SAMPLES);

  // Calculating wind value.
  int32_t timeWithWindLeft;
  timeWithWindLeft = processed.deltaTimeLeft + samples->timeWithoutWind;
  int32_t timeWithWindRight;
  timeWithWindRight = processed.deltaTimeRight + samples->timeWithoutWind;
  int64_t windSpeed = 100000000LL * TRANSCEIVER_DISTANCE;
  windSpeed *= (timeWithWindRight - timeWithWindLeft);
  windSpeed /= 2LL * timeWithWindLeft * timeWithWindRight;

  bool directionRight;
  if(windSpeed >= 0) {
    directionRight = true;
  } else {
    directionRight = false;
    windSpeed *= -1;
  }

  // Displaying wind value.
  char stringToDisplay[17];
  sprintf(stringToDisplay,"%.2d,%.2d m/s   %s", (int16_t)(windSpeed / 100),
          (int16_t)(windSpeed % 100), directionRight ? "-->" : "<--");
  putText(stringToDisplay);
}

inline uint64_t calcTimeWithoutWind(int8_t temperature) {
  return (1000000000ULL * TRANSCEIVER_DISTANCE / (331300 + 606 * temperature));
}

/**
  * @brief  Interrupt occurs during sending impulses to ultrasonic transceiver.
  */
ISR(TIMER1_COMPA_vect) {
  static uint8_t cycles = 0;
  cycles++;

  // After 20 periods.
  if(cycles == 40) {
    // Timer stop.
    TCCR1B &= ~_BV(CS10);
    cycles = 0;

    // Wait for ultrasonic impulse to travel to another transceiver.
    _delay_us(50);

    // Collect signal data from transceiver.
    for(uint16_t i = 0; i < SAMPLE_NUMBER; i++) {
      // This operation takes exactly 152 cycles
      // which is 6333 ns for 24 MHz clock.
      getDataFromAdc(&samplesTmp[i]);
    }
    dataCollected = true;
  }
}

/**
  * @brief  Interrupt occurs regularly every 10.92 ms.
  *         Doesn't block other interrupt because its time is not critical.
  */
ISR(TIMER0_OVF_vect, ISR_NOBLOCK) {
  static uint8_t tickCount = 0;
  static bool calibrationInitiated = false;

  static uint8_t tickLedCount = 0;
  tickLedCount++;

  // Switches status LED every 1 s.
  if(tickLedCount == 92) {
    tickLedCount = 0;
    LED_PORT ^= _BV(LED);
  }

  // If calibration button is hold for at least 2 s, calibration will occur.
  if(~(BUTTON_PIN) & _BV(BUTTON_CALIBRATION)) {
    tickCount++;
    if(!calibrationInitiated && tickCount == 183) {
      calibrationInitiated = true;
      calibrationInProgress = true;
    }
  } else {
    tickCount = 0;
    if(!calibrationInProgress)
    calibrationInitiated = false;
  }
}

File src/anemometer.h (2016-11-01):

/**
  ******************************************************************************
  * @file    anemometer.h
  * @author  Karol Leszczyński
  * @version V1.0.0
  * @date    08-August-2015
  * @brief   Configuration defines and struct definitions.
  ******************************************************************************
  * @attention
  *
  * This file is part of Ultrasonic_Anemometer.
  *
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
  ******************************************************************************
  */

#ifndef ANEMOMETER_H_
#define ANEMOMETER_H_

#include <avr/io.h>

// Number of samples in signal.
#define SAMPLE_NUMBER 480

// Maximum delay of cross correlation.
#define MAX_DELAY 36

// Number of regression samples.
#define REGRESSION_SAMPLES 31

// Distance between ultrasonic transceivers.
#define TRANSCEIVER_DISTANCE 270

// Ultrasound generator and multiplexer.
#define GENERATOR_PORT PORTD
#define GENERATOR_DDR  DDRD
#define GENERATOR_OUT  PD5
#define MPLEXER_SWITCH PD6
// This value causes generator to generate signal at frequency 40268 Hz.
#define GENERATOR_TIMER_TICKS 297

// Calibration button.
#define BUTTON_PIN         PINB
#define BUTTON_CALIBRATION PB0

// Status LED.
#define LED_DDR  DDRB
#define LED_PORT PORTB
#define LED      PB1

// SPI interface.
#define SPI_PORT PORTB
#define SPI_DDR  DDRB
#define SPI_MOSI PB5
#define SPI_MISO PB6
#define SPI_SCK  PB7
#define SPI_SS   PB4

// DS1820 sensor.
#define DS1820_PORT PORTB
#define DS1820_DDR  DDRB
#define DS1820_PIN  PINB
#define DS1820_DQ   PB2

/**
  * @brief  Collected samples and other data needed for processing.
  */
typedef struct Samples {
  int16_t left[SAMPLE_NUMBER];            /**< Left transceiver samples from ADC. */
  int16_t right[SAMPLE_NUMBER];           /**< Right transceiver samples from ADC. */
  int16_t fromEepromLeft[SAMPLE_NUMBER];  /**< Left transceiver samples from EEPROM. */
  int16_t fromEepromRight[SAMPLE_NUMBER]; /**< Right transceiver samples from EEPROM. */
  int8_t temperature;                     /**< Measured temperature. */
  uint64_t timeWithoutWind;               /**< Calculated signal time of flight without wind. */
  uint16_t samplesNumber;                 /**< Number of samples for processing. */
} Samples;

/**
  * @brief  Data generated during signal processing.
  */
typedef struct Processed {
  int32_t deltaTimeLeft;                               /**< Left transceiver delay between cross correlated signals. */
  int32_t deltaTimeRight;                              /**< Right transceiver delay between cross correlated signals. */
  int32_t highestCorrelationLeft[REGRESSION_SAMPLES];  /**< Left transceiver highest samples from correlation. */
  int32_t highestCorrelationRight[REGRESSION_SAMPLES]; /**< Right transceiver highest samples from correlation. */
  uint8_t highestCorrelationLength;                    /**< Number of highest samples from correlation. */
} Processed;

#endif /* ANEMOMETER_H_ */

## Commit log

2016-03-03 Added sample images.
2016-11-02 Added Eagle schematic files.
    [ultrasonic_anemometer_pcb.brd, ultrasonic_anemometer_pcb.sch, ultrasonic_anemometer_schematic.sch]
2016-11-02 Small fixes on Eagle pcb schematic.
    [ultrasonic_anemometer_pcb.brd]
2016-11-02 Added images of schematic and pcb.
2016-11-10 Small fix in ADC driver.

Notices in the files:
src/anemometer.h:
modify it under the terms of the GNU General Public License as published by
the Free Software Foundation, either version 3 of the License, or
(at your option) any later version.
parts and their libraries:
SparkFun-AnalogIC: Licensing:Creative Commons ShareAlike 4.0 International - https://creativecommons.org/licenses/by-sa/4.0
